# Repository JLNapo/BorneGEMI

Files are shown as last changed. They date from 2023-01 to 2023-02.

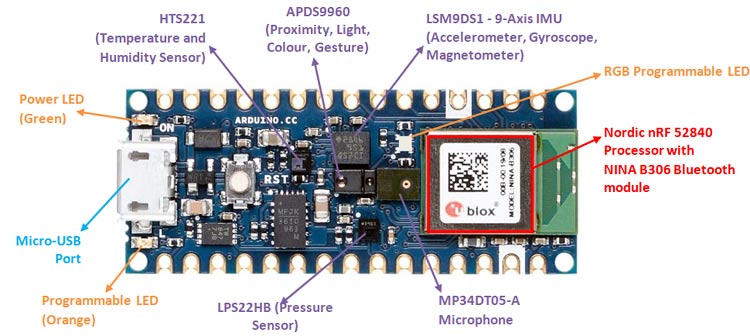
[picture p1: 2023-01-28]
Images/Nano-33-BLE-Sense-Hardware-Overview.jpg

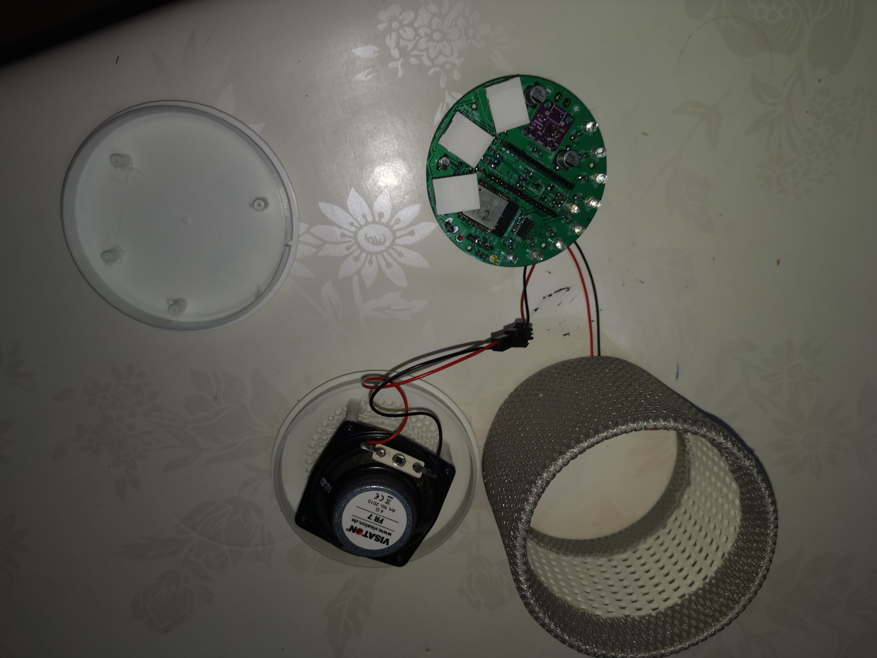
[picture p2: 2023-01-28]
Images/img06.jpg

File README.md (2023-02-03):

# Enceinte-Connectée-Domotique
Créer une enceinte connectée pour votre domotique est possible à moindre frais.

Une enceinte connectée avec peu d'élément et capable de commander votre domotique sans passer par un serveur externe est faisable facilement avec des éléments Arduino et un  peu d'électronique.
Cette borne (appelons la comme cela) est principalement composée de 2 processeurs.
- Un Arduino NANO 33 BLE Sense modèle ABX0035 (maintenant remplacé par ABX0070, même fonctionnement mais librairie différentes)
- Un ESP-WROOM-32 module prenant moins de place que les ESP32 et tout leur système de connexion et programmation.
- Un TTL 74HC595 (registre à décalage) permettant la gestion de 8 LEDs pour le réglage du volume (principalement)
- 9 LEDs dont une RVB piloté par 3 transistors afin de ne pas surcharger les GPIO de l'ESP32
- Quelques resistances
- des connecteurs
- Une alimentation secteur à sortie 5V 1,5A ou plus (1A permet le fonctionnement, mais il est préférable de garder une marge)
- Un haut parleur
- Un boitier fait avec une imprimante 3D (3 pièces)
- Un peu de tissus spécial haut parleur (un tissus à mailles pas très serré peu convenir)

# Logiciels employés:
- Picovoice (https://console.picovoice.ai)
- Voicerss (http://api.voicerss.org)
- Arduino IDE (Ver. 1.8.19.0)
- Sketchup 17 (Google gratuit) boitier 3D
- Cura (Ver. 5.0.0.0) pour le GCode
- Editplus (pour les pages WEB) Notepad++ ou tout autre éditeur peut convenir.
- Kicad 5.0 pour la conception du circuit imprimé (réalisation chez JLCPCB https://jlcpcb.com)

# Librairies ESP32
- WebServer.h
- WiFiClient.h
- WiFi.h
- WiFiMulti.h
- Update.h
- WiFiUdp.h
- "RTClib.h"
- Audio.h
- SPIFFS.h
- HardwareSerial.h
- "ESP8266FtpServer.h"
- "OTApage.h" (données pour la mise à jour par le WEB)
- "esp32_ping.h"

# Librairie NANO 33 BLE Sense
- Picovoice_FR.h (plusieurs langues disponnibles)
- "params.h" (données obtenues sur le site Picovoice)

# Matériel pour le boitier (plusieurs essais) j'ai 4 imprimantes 3D ça aide:
- Imprimante 3D Tenlog TL-D3 Pro
- Artillery Sidewinder X2
- Elegoo Saturn (résine)
- Leapfrog (pas utilisé)
- Tissus Haut Parleur Audio acheté sur Amazon.fr

<b>Nota:</b> toutes imprimantes peut convenir (en tenant compte des dimensions)

Vous trouverez ici l'ensemble de la réalisation ainsi qu'une courte vidéo.
# Réalisation
Cette version est une version beta et correspond à ma domotique qui est quasiment entièrement faite par moi au fil du temps.
J'ai commencé la domotique vers la fin des années 80. Jusque là (et c'est toujours le cas) c'est mon serveur qui tourne 24/7 qui s'en occupait totalement, mais ces dernières années avec l'arrivé des enceintes connectées (j'ai 3 "Google Home" et 2 "Amazon Alexa") mais Google s'est retiré de IFTTT, du coup cela devenait moins pratique pour moi qui ait plus d'objets connectés DIY que du commerce, alors j'ai décidé de créer la mienne et de partager mon expérience avec vous.<br/>
J'en ai construit 3 (pour le moment) qui donne satisfaction au quotidien et sans solliciter aucun serveur externe, certaine réponses des objets connectés sont du texte qui ne peut pas être traité en TTS par l'ESP32, alors j'envoi au serveur Voicerss le texte et je stream le mp3 créé en temps réel sans saturer le SPIFFS de l'ESP32 et la réponse est quasi instantannée. Les commandes et réponses se font au même rytme qu'avec les enceintes connectées du marché mais je n'ai pas recourt à un serveur pour connaitre la commande et l'exécuter (protection des données personnelles)
# Aide
Je suis ouvert à toutes suggestions ou questions et même à une aide (dans la mesure du possible)<br/>
Je peux fournir les fichiers du CI (fichiers Kicad) par exemple.

<b>Nota:</b> Ce partage ne peut en aucun cas faire l'objet de fabrications commerciales, et n'est là qu'a titre ludique pour des amateurs comme moi désireux de garder pour soit des informations qui sont souvent exploitées par les grandes firmes lors de nos commandes vocales par le biais de celles ci.

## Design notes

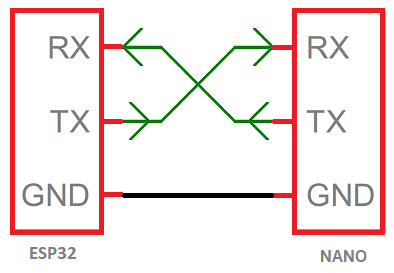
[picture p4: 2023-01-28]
Images/ESP32 Serial communication.png

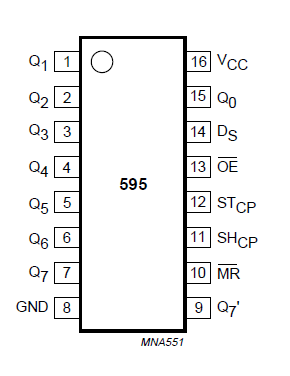
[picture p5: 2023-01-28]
Images/74HC595-01.png

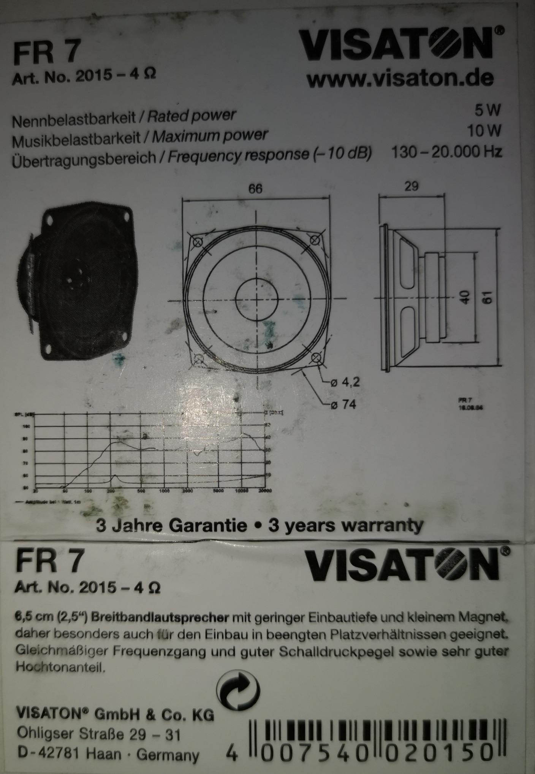
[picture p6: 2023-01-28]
Images/HP-BorneGEMI.jpg

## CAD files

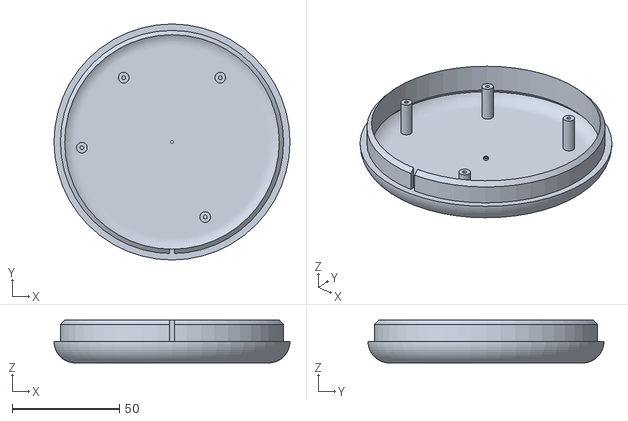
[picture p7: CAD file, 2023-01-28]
Fichiers 3D/BGR_Haut.stl
110.0 x 110.0 x 20.0

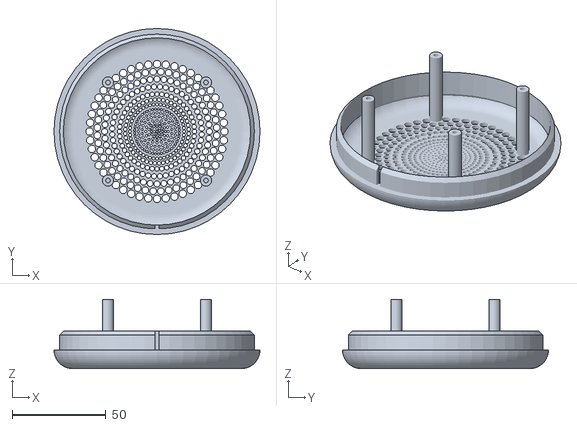
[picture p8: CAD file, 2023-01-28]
Fichiers 3D/BGR_Bas.stl
110.0 x 110.0 x 37.0

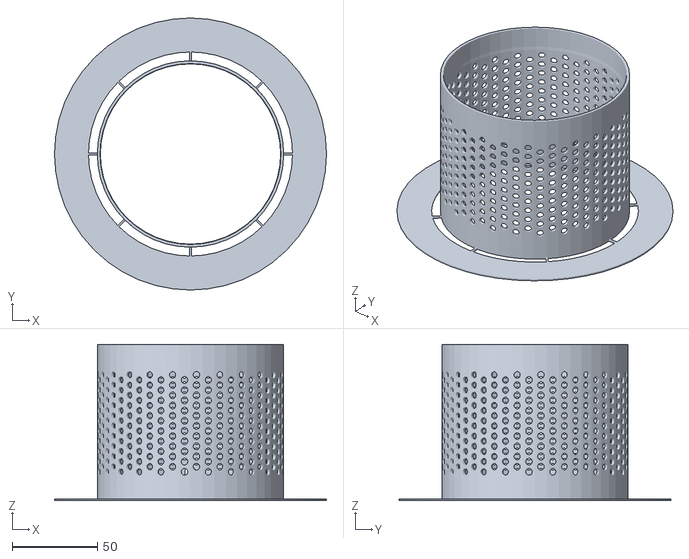
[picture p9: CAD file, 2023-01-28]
Fichiers 3D/BGR_Centre.stl
160.0 x 160.0 x 92.0

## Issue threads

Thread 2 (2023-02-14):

Version 0.2.2.1

JLNapo, 2023-02-14:
Ajout et amélioration de certaines fonctions.
Montage de la quatrième "Borne" avec cette fois un ABX00070 NANO 33 BLE Sense version 2.
Uniformisation des fonctions pour compatibilité ABX00035 et ABX00070.
Très peu de "faux positifs" déclenchés par la radio ou la télévision et ils ne sont de toute façon pas traité (pas de lumière qui s'allume non désirée)

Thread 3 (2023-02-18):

Version 0.2.2.3

JLNapo, 2023-02-18:
Les fonctions d'alarmes, de déclenchement de celles-ci et d'autres fonctions ont été ajoutées.

etiennes33, 2023-12-23:
Bonjour, et félicitations pour ce développement ! J'aimerais bien me lancer dans quelque chose d'équivalent, et j'aurais 2 questions à propos de ce montage.
Quel est approximativement le temps de réponse entre la fin de l'ordre prononcé et l'envoi de la trame correspondante vers l'UART une fois décodé par la carte nano ?
Et surtout, j'ai tenté de m'inscrire sur picovoice, et là surprise, le site n'accepte pas mon email ! Quelle type d'email avez-vous utilisé pour vous inscrire ?
En vous remerciant pour le travail que vous avez accompli et qui va me faire gagner beaucoup de temps :-)

JLNapo, 2023-12-23:
Bonjour,

Le temps de réponse d’une borne est très rapide, si vous avez déjà une borne « Google » ou « Amazon » les temps de réponse sont similaires, sans avoir à communiquer avec un serveur distant.

Le seul serveur auquel je fais appel quand cela est nécessaire, c’est mon serveur domotique situé au sous sol, serveur dans lequel toutes les applications ont été développé par mes soins.

La borne déposée sur forum et github a évoluée, j’en possède 4 et je n’ai jamais eu de fonctionnement non désiré. Il arrive que l’on prononce quelques fois quelques chose proche du mot d’appel (pour moi : « ok GEMI »)

La borne émet le son qui est sensé dire qu’elle attend un ordre, mais si l’ordre n’est pas reconnu (simple conversation ou télé/radio etc.) elle retourne à son état normale d’attente.

Au début je lui faisais dire qu’une erreur était survenue, mais cela peut devenir dérangeant, alors maintenant elle se tait et attend un nouvel ordre (comme les bornes officielle).

Tout cela c’est juste de la programmation, et il faut faire beaucoup d’essai avant de trouver les bons compromis.

Pour picovoice, j’utilise 2 adresses email (chez free) comme cela ça me permet de faire des tests malgré la limitation du nombre autorisé par mois.

Au début Picovoice autorisait un nombre illimité, mais il sont rapidement parvenu à une limitation, car la vente de leurs fonctions est leur gagne pain.

Ce qui est pratique, c’est qu’on peut enregistrer ou charger le fichier créé sur le site et on peut ainsi faire des modifications hors ligne (fichier YML, donc texte) et le recharger lors d’un autre essai.

L’inconvénient, c’est que les fichiers permettant la compilation Pour le Nano est déjà précompilé (pour la partie commandes) et qu’on l’ajoute simplement  (en partie) dans notre programme sur le Nano.

Pour le Nano, attention il en existe plusieurs modèle, celui compatible, est seulement le « Nano 33 BLE Sense ».

Il faut utiliser la clé (fournie lors de l’inscription) avec le Numéro de série, obtenu par un programme fourni par le site, car la compilation ne fonctionnera qu’avec ces paramètres (test effectué par moi)

Il m’ont aussi demander de faire paraitre mon expérience en utilisant leurs fonctions, je leur ait répondu que je n’étais sur aucun réseau social (et je ne compte pas y être de si tôt)

Mais dans le soucis de partage (ce que je fais souvent) je donne des tuyaux ça et là sur le net, mais sans jamais rien attendre en retour.

Si je peux aider, c’est toujours avec joie que je le fais, si on est passionné d’électronique ou de développement, on ne compte pas son temps.

Voilà pour les informations demandées, et en vous souhaitant de passer de très bonnes fêtes de fin d’année .

Cordialement,

Jean-Luc

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

etiennes33, 2023-12-23:
Merci pour cette réponse rapide, je vous posais la question de l'email
car j'ai une adresse free et une autre yahoo, et aucune n'est acceptée.
D'ailleurs en faisant beaucoup d'essais, je me suis rendu compte
qu'aucune adresse issue des grands pourvoyeurs d'adresse (orange, free,
yahoo, gmail, etc...) n'est acceptée. Seules sont acceptées les adresses
de sociétés, je vais donc devoir aviser.

J'ai vu qu'il existe maintenant plusieurs versions du Nano 33 BLE Sense,
notamment ABX00031, ABX00032, ABX00034, ABX00069, ABX00070. Compliqué de
s'y retrouver là-dedans. Lesquels avez-vous utilisé et dont je serai
certain qu'ils fonctionnent , pour que j'évite de chercher un bug
pendant des heures ?

Encore merci pour ce projet, car s'il existe beaucoup de pages internet
sur le sujet, il y a beaucoup de bla-bla et de pub, mais il est
difficile de trouver une vraie réalisation qui fonctionne ! En fait, je
n'ai trouvé que la vôtre qui comporte des sources utilisables ...

Et passez de bonne fêtes de fin d'année !

Etienne

Le 2023-12-23 14:09, JLNapo a écrit :

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

Links:
------
[1] https://github.com/JLNapo/BorneGEMI/issues/3#issuecomment-1868291579
[2]
https://github.com/notifications/unsubscribe-auth/BE4CWXFP77WCDMJTSWAPL3TYK3JXJAVCNFSM6AAAAAAVAHLYI6VHI2DSMVQWIX3LMV43OSLTON2WKQ3PNVWWK3TUHMYTQNRYGI4TCNJXHE
--=_0aaed55ec9d0f3b734d613766a375867
Content-Type: multipart/related;
 boundary="=_70d6374599e5a1d67da88dd9bc7d7d4b"

--=_70d6374599e5a1d67da88dd9bc7d7d4b
Content-Transfer-Encoding: quoted-printable
Content-Type: text/html; charset=UTF-8

<html><head><meta http-equiv=3D"Content-Type" content=3D"text/html; charset=
=3DUTF-8" /></head><body style=3D'font-size: 10pt; font-family: Verdana,Gen=
eva,sans-serif'>
<p>Merci pour cette r&eacute;ponse rapide, je vous posais la question de l'=
email car j'ai une adresse free et une autre yahoo, et aucune n'est accept&=
eacute;e. D'ailleurs en faisant beaucoup d'essais, je me suis rendu compte =
qu'aucune adresse issue des grands pourvoyeurs d'adresse (orange, free, yah=
oo, gmail, etc...) n'est accept&eacute;e. Seules sont accept&eacute;es les =
adresses de soci&eacute;t&eacute;s, je vais donc devoir aviser.</p>
<p>J'ai vu qu'il existe maintenant plusieurs versions du Nano 33 BLE Sense,=
 notamment ABX00031, ABX00032, ABX00034, ABX00069, ABX00070. Compliqu&eacut=
e; de s'y retrouver l&agrave;-dedans. Lesquels avez-vous utilis&eacute; et =
dont je serai certain qu'ils fonctionnent , pour que j'&eacute;vite de cher=
cher un bug pendant des heures ?</p>
<p>Encore merci pour ce projet, car s'il existe beaucoup de pages internet =
sur le sujet, il y a beaucoup de bla-bla et de pub, mais il est difficile d=
e trouver une vraie r&eacute;alisation qui fonctionne ! En fait, je n'ai tr=
ouv&eacute; que la v&ocirc;tre qui comporte des sources utilisables ...</p>
<p>Et passez de bonne f&ecirc;tes de fin d'ann&eacute;e !</p>
<p>Etienne</p>
<p><br /></p>
<p><br /></p>
<p><br /></p>
<p id=3D"reply-intro">Le 2023-12-23 14:09, JLNapo a &eacute;crit&nbsp;:</p>
<blockquote type=3D"cite" style=3D"padding: 0 0.4em; border-left: #1010ff 2=
px solid; margin: 0">
<div id=3D"replybody1">
<p><br /></p>
Bonjour, <br /><br /><br /><br />Le temps de r&eacute;ponse d'une borne est=
 tr&egrave;s rapide, si vous avez d&eacute;j&agrave; une borne &laquo; Goog=
le &raquo; ou &laquo; Amazon &raquo; les temps de r&eacute;ponse sont simil=
aires, sans avoir &agrave; communiquer avec un serveur distant. <br /><br /=
>Le seul serveur auquel je fais appel quand cela est n&eacute;cessaire, c'e=
st mon serveur domotique situ&eacute; au sous sol, serveur dans lequel tout=
es les applications ont &eacute;t&eacute; d&eacute;velopp&eacute; par mes s=
oins. <br /><br />La borne d&eacute;pos&eacute;e sur forum et github a &eac=
ute;volu&eacute;e, j'en poss&egrave;de 4 et je n'ai jamais eu de fonctionne=
ment non d&eacute;sir&eacute;. Il arrive que l'on prononce quelques fois qu=
elques chose proche du mot d'appel (pour moi : &laquo; ok GEMI &raquo;) <br=
 /><br />La borne &eacute;met le son qui est sens&eacute; dire qu'elle atte=
nd un ordre, mais si l'ordre n'est pas reconnu (simple conversation ou t&ea=
cute;l&eacute;/radio etc.) elle retourne &agrave; son &eacute;tat normale d=
'attente. <br /><br />Au d&eacute;but je lui faisais dire qu'une erreur &ea=
cute;tait survenue, mais cela peut devenir d&eacute;rangeant, alors mainten=
ant elle se tait et attend un nouvel ordre (comme les bornes officielle). <=
br /><br />Tout cela c'est juste de la programmation, et il faut faire beau=
coup d'essai avant de trouver les bons compromis. <br /><br /><br /><br />P=
our picovoice, j'utilise 2 adresses email (chez free) comme cela &ccedil;a =
me permet de faire des tests malgr&eacute; la limitation du nombre autoris&=
eacute; par mois. <br /><br />Au d&eacute;but Picovoice autorisait un nombr=
e illimit&eacute;, mais il sont rapidement parvenu &agrave; une limitation,=
 car la vente de leurs fonctions est leur gagne pain. <br /><br />Ce qui es=
t pratique, c'est qu'on peut enregistrer ou charger le fichier cr&eacute;&e=
acute; sur le site et on peut ainsi faire des modifications hors ligne (fic=
hier YML, donc texte) et le recharger lors d'un autre essai. <br /><br />L'=
inconv&eacute;nient, c'est que les fichiers permettant la compilation Pour =
le Nano est d&eacute;j&agrave; pr&eacute;compil&eacute; (pour la partie com=
mandes) et qu'on l'ajoute simplement (en partie) dans notre programme sur l=
e Nano. <br /><br />Pour le Nano, attention il en existe plusieurs mod&egra=
ve;le, celui compatible, est seulement le &laquo; Nano 33 BLE Sense &raquo;=
=2E <br /><br />Il faut utiliser la cl&eacute; (fournie lors de l'inscripti=
on) avec le Num&eacute;ro de s&eacute;rie, obtenu par un programme fourni p=
ar le site, car la compilation ne fonctionnera qu'avec ces param&egrave;tre=
s (test effectu&eacute; par moi) <br /><br />Il m'ont aussi demander de fai=
re paraitre mon exp&eacute;rience en utilisant leurs fonctions, je leur ait=
 r&eacute;pondu que je n'&eacute;tais sur aucun r&eacute;seau social (et je=
 ne compte pas y &ecirc;tre de si t&ocirc;t) <br /><br />Mais dans le souci=
s de partage (ce que je fais souvent) je donne des tuyaux &ccedil;a et l&ag=
rave; sur le net, mais sans jamais rien attendre en retour. <br /><br />Si =
je peux aider, c'est toujours avec joie que je le fais, si on est passionn&=
eacute; d'&eacute;lectronique ou de d&eacute;veloppement, on ne compte pas =
son temps. <br /><br /><br /><br />Voil&agrave; pour les informations deman=
d&eacute;es, et en vous souhaitant de passer de tr&egrave;s bonnes f&ecirc;=
tes de fin d'ann&eacute;e . <br /><br />Cordialement, <br /><br />Jean-Luc =
<br /><br /><br /><br /><br /><br />De : etiennes33 ***@***.*** <br />Envoy=
&eacute; : samedi 23 d&eacute;cembre 2023 13:28 <br />&Agrave; : JLNapo/Bor=
neGEMI <br />Cc : JLNapo; Author <br />Objet : Re: [JLNapo/BorneGEMI] Versi=
on 0.2.2.3 (Issue #3) <br /><br /><br /><br />Bonjour, et f&eacute;licitati=
ons pour ce d&eacute;veloppement ! J'aimerais bien me lancer dans quelque c=
hose d'&eacute;quivalent, et j'aurais 2 questions &agrave; propos de ce mon=
tage. <br />Quel est approximativement le temps de r&eacute;ponse entre la =
fin de l'ordre prononc&eacute; et l'envoi de la trame correspondante vers l=
'UART une fois d&eacute;cod&eacute; par la carte nano ? <br />Et surtout, j=
'ai tent&eacute; de m'inscrire sur picovoice, et l&agrave; surprise, le sit=
e n'accepte pas mon email ! Quelle type d'email avez-vous utilis&eacute; po=
ur vous inscrire ? <br />En vous remerciant pour le travail que vous avez a=
ccompli et qui va me faire gagner beaucoup de temps :-) <br /><br />&mdash;=
 <br />Reply to this email directly, view it on GitHub &lt;https://github.c=
om/JLNapo/BorneGEMI/issues/3#issuecomment-1868284471&gt; , or unsubscribe &=
lt;https://github.com/notifications/unsubscribe-auth/ABOHRTFVNPZBLX2UO7GCWD=
3YK3E3FAVCNFSM6AAAAAAVAHLYI6VHI2DSMVQWIX3LMV43OSLTON2WKQ3PNVWWK3TUHMYTQNRYG=
I4DINBXGE&gt; . <br />You are receiving this because you authored the threa=
d. &lt;https://github.com/notifications/beacon/ABOHRTC4Z2GFJPNGFRVSHK3YK3E3=
FA5CNFSM6AAAAAAVAHLYI6WGG33NNVSW45C7OR4XAZNMJFZXG5LFINXW23LFNZ2KUY3PNVWWK3T=
UL5UWJTTPLPBDO.gif&gt; Message ID: ***@***.***&gt; <br /><br />
<p style=3D"font-size: small; -webkit-text-size-adjust: none; color: #666;"=
>&mdash;<br />Reply to this email directly, <a href=3D"https://github.com/J=
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

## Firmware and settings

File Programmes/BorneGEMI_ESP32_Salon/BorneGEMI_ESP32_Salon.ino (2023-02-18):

/*
 * Gestion de la borne *** Salon
 * Cette partie de la borne execute les commandes et correspond avec *** pour celles qu'il ne peut traiter.
 *
 * Processeur ESP32 (DOIT ESP32 DEVKIT V1)
 * Amplificateur: MAX98357A (3w)
 * LED pilotées par : 74HC595 (8-bit serial - in / serial or parallel - out shift register with output latches 3 - state)
 * Touches sensitives
 *
 * Proc. IDE arduino  : DOIT ESP32 DEVKIT V1
 * Proc. RTC (heure)  : DS3231 (sauvegardé par batterie)
 * Mot de passe WEB   : ***
 * Mot de passe MAJ   : ***
 *
 * IMPORTANT: - Remplacer "***" par vos données.
 *            - Remplacer GEMI ou gémi par le nom de votre système domotique
 *
 */

#include <WebServer.h>
#include <WiFiClient.h>
#include <WiFi.h>
#include <WiFiMulti.h>
#include <Update.h>
#include <WiFiUdp.h>
#include "RTClib.h"
#include <Audio.h>
#include <SPIFFS.h>
#include <HardwareSerial.h>
#include "ESP8266FtpServer.h"
#include "OTApage.h"
#include "esp32_ping.h"

/* Necessaire au Réseau WiFi */
String SysDomo = "GEMI";                                                              // Nom donné au système domotique (pour moi GEMI => Gestion Electronique de Maison Individuelle)
String MyName = SysDomo + "_Salon";                                                   // Nom visible sur le réseau <= Si nécessaire la fonction ESP.getChipId() peut ajouter l'ID de la puce à la fin.
int nbReseauWiFi = 4;                                                                 // Nombre de réseaux disponnibles dans le lieu (pour moi 4)
String ssid1 = "WiFi_1";                                                              // SSID (Nom du reseau wifi)
String pass1 = "MDP WiFi 1";                                                          // Password (Mot de passe wifi)
String ssid2 = "WiFi_2";                                                              // SSID (Nom du reseau wifi)
String pass2 = "MDP WiFi 2";                                                          // Password (Mot de passe wifi)
String ssid3 = "WiFi_3";                                                              // SSID (Nom du reseau wifi)
String pass3 = "MDP WiFi 3";                                                          // Password (Mot de passe wifi)
String ssid4 = "WiFi_4";                                                              // SSID (Nom du reseau wifi)
String pass4 = "MDP WiFi 4";                                                          // Password (Mot de passe wifi)
IPAddress ipAdresse(192, 168, ***, ***);                                              // IP locale de ce module (fourni par le serveur dns, normalement la Box)
IPAddress gateway(192, 168, ***, ***);                                                // L'IP de la box
IPAddress subnet(255, 255, 255, 0);                                                   // Mask réseau
IPAddress dns(192, 168, ***, ***);                                                    // L'IP de la box (ou d'un serveur NTP)
const uint32_t connectTimeoutMs = 10000;                                              // Tmeout de connexion WiFiMulti
String MyIP = "";                                                                     // Contient l'adresse IP avec séparateur (point) comme chaine
String MAC = "";                                                                      // Adresse MAC du module (peut servir pour éventuellement paramétrer la box)
String MySSID = "";
String MyPass = "";
String FTPuser = "Utilisateur FTP";                                                   // Utilisateur FTP
String FTPpass = "MDP FTP";                                                           // Mot de passe FTP
String OTApass = "MDP OTA";                                                           // Mot de passe OTA
char USR_WEB[] = "Utilisateur WEB";                                                   // Utilisateur pour le web (indispensable)
char PSS_WEB[] = "MDP WEB";                                                           // Mot de passe pour le web (indispensable)
bool Log = false;                                                                     // Enregistrer dans un fichier Log les différentes actions
byte LogMois = 0;                                                                     // Mois en cours pour les Log

String VoiceRss = F("http://api.voicerss.org/?key=***&hl=fr-fr&c=MP3&f=32khz_16bit_mono&src=");
String UID_Nano = F("***");
String Access_Key = F("***");

/************************************** CE QUI EST AU DESSUS DE CETTE LIGNE EST SPECIFIQUE A CHAQUE BORNE, AU DESSOUS TOUT EST COMMUN A TOUTES LES BORNES *******************************************************/

const char Version[] = "0.2.2.3";

/* I2S Connexion et boutons */
#define I2S_DOUT        25                                                            // I2S pour la connexion avec l'ampli MAX98357A
#define I2S_BCLK        26
#define I2S_LRC         27
#define Serial_RX       16                                                            // 16 et 17 servent au port série de communication avec le NANO 33 BLE Sense
#define Serial_TX       17
#define bgClock         13                                                            // Clock du 74HC595 (BarGraph)
#define bgLatch         12                                                            // Latch du 74HC595 (BarGraph)
#define bgData          14                                                            // Data  du 74HC595 (BarGraph)
#define btnPlus         19                                                            // Bouton "plus" volume (Touche sensitive capacitive)
#define btnMoins        18                                                            // Bouton "moins" volume (Touche sensitive capacitive)
#define btnMicro        23                                                            // Bouton Arrêt/Marche micro (en réalité pas d'interprétation de ce qui est entendu) (Touche sensitive capacitive)
#define ledMicro        33                                                            // (Rvb) LED Arrêt/Marche micro (en réalité pas d'interprétation de ce qui est entendu) (partie rouge de la LED RVB)
#define ledEcoute       32                                                            // (rvB) LED Arrêt/Marche écoute (allumé avec "Hé! GÉMI" et s'éteint après la commande ou l'abandon utilisateur après ~5/6s ou commande non comprise (avec message).
#define ledWiFi         15                                                            // (rVb) Allumée pendant la mise à l'heure ou la connexion WiFi (verte)
                                                                                      // Etat des couleurs de la LED RVB => Rouge = micro coupé (juste pas d'analyse). Bleu = écoute de cde. Verte = Pas de WiFi ou Mise à l'heure en cours.
/* Diverses variables */
int Volume = 15;                                                                      // Volume par défaut au premier démarrage
int VolDef = 15;                                                                      // Volume par défaut pour certaine réponse importante (ex: alarme arrivée à son terme)
int Grave = 6;                                                                        // Niveau des graves pour le son sortant du haut parleur
int Medium = 4;                                                                       // Niveau des mediums pour le son sortant du haut parleur
int Aigue = -7;                                                                        // Niveau des aigues pour le son sortant du haut parleur
bool VolReg = false;                                                                  // Pour enregistrer après un temps le réglage du volume depuis la borne
bool LedReg = false;                                                                  // Pour l'allumage des leds de volume
int LedVal = 1;                                                                       // Valeur des LEDs allumées
const uint8_t VolumeTable[8]={1, 3, 7, 15, 31, 63, 127, 255};                         // 8 elements (8 LEDs)
bool Micro = true;                                                                    // Micro en fonction (par défaut à true)
unsigned long VolMillis;                                                              // Temporisation avant de sauvegarder la valeur du volume
unsigned long LedMillis;                                                              // Temporisation avant l'exctinction des leds
byte NumStation = 1;                                                                  // Station par défaut
byte NbreRadios = 22;                                                                 // Nombre maxi de Stations de radio
byte NbreBornes = 3;                                                                  // Nombre maxi de bornes domotique
String RadioOld = "";                                                                 // Lien http vers la station de radio en cours.
bool RadioON = false;                                                                 // Passe à true quand la radio marche, sinon false
bool BtnON = false;                                                                   // Flag bouton appuyé
bool TouchON = false;                                                                 // Flag Touche sensitive appuyée
String startString = "";                                                              // Date heure de démarrage
String webString = "";
bool bgReg[8];                                                                        // Registre à décalage du 74HC595
bool bgSens = false;
bool Fait = false;                                                                    // Commande terminée
bool HandShakeWait = false;                                                           // Passe à true si l'ESP32 recois "open" (ouverture d'une commande => le NANO entend "Hé GEMI" et envoi "open" à l'ESP32). L'ESP32 joue le son "on.mp3" et envoi "ready" au NANO (HandShake)
bool HandShakeState = false;                                                          // Statut du HandShake de toute la commande => passe à true au début et ne passe à false que lorsque toute la commande est terminée (réponse de l'objet connecté comprise).
unsigned long HandShakeMillis;                                                        // Pour le timeout du "HandShake" en cas d'un faux positif.
int HandShakeTimeout = 10000;                                                         // Nombre de millisecondes du timeout de la communication NANO/ESP32 ("HandShake")
bool AudioState = false;                                                              // Passe à true au début de lecture d'un MP3 et à false lorsque c'est terminé.
bool Alarme = false;                                                                  // Pour le déclenchement d'une alarme (ex: "mets une alarme dans 10mn" ou "mets une larme à 10H15")
bool AlarmeEtape = false;                                                             // Fait sonner l'alarme une deuxième fois au bout de 5s
uint32_t AlarmeEnSeconde = 0;                                                         // Temps en secondes pour la programmation de l'alarme
float TempOffSet = 0.0;                                                               // OffSet (décalage) de la température mesurée (pour tenir compte de la température dûe au fonctionnement de l'électronique)
bool TestLEDStart = false;                                                            // Faire un test des LEDs au démarrage (oui/non => Defaut: NON) on peut régler ce paramètre ou faire un test depuis la page WEB.

/* functions qui retournent la date en strings (char) en francais */
// Longueur des chaînes pour chaque jour ou mois
#define SECS_PER_HOUR ((time_t)(3600UL))                                              // Necessaire au calcul en fonction de l'heure recueillie par NTP.
#define dt_SHORT_STR_LEN  3                                                           // La longueur des chaînes courtes pour les ou les mois
#define dt_MAX_STRING_LEN 9                                                           // Longueur de la chaîne de date la plus longue (hors null de fin)
static char buffer[dt_MAX_STRING_LEN+1];                                              // Doit être suffisamment grand pour la chaîne la plus longue et la valeur null de fin
const PROGMEM char * const PROGMEM monthNames_P[] = {"Décembre","Janvier","Février","Mars","Avril","Mai","Juin","Juillet","Aout","Septembre","Octobre","Novembre","Décembre"};
const PROGMEM char * const PROGMEM dayNames_P[] = {"Dimanche","Lundi","Mardi","Mercredi","Jeudi","Vendredi","Samedi","Dimanche"};
const char dayShortNames_P[] PROGMEM = "DimLunMarMerJeuVenSam";
const char monthShortNames_P[] PROGMEM = "ErrJanFevMarAvrMaiJunJulAouSepOctNovDec";

char* monthStr(uint8_t month) {
  strcpy_P(buffer, (PGM_P)pgm_read_ptr(&(monthNames_P[month])));
  return buffer;
}

char* monthShortStr(uint8_t month) {
  for (int i=0; i < dt_SHORT_STR_LEN; i++)
    buffer[i] = pgm_read_byte(&(monthShortNames_P[i+ (month*dt_SHORT_STR_LEN)]));
  buffer[dt_SHORT_STR_LEN] = 0;
  return buffer;
}

char* dayStr(uint8_t day) {
  strcpy_P(buffer, (PGM_P)pgm_read_ptr(&(dayNames_P[day])));
  return buffer;
}

char* dayShortStr(uint8_t day) {
  uint8_t index = day*dt_SHORT_STR_LEN;
  for (int i=0; i < dt_SHORT_STR_LEN; i++)
    buffer[i] = pgm_read_byte(&(dayShortNames_P[index + i]));
  buffer[dt_SHORT_STR_LEN] = 0;
  return buffer;
}
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
void loop() {
  server.handleClient();
  ftpSrv.handleFTP();
  now = rtc.now();
  audio.loop();

  /* Changement de jour et forcer une mise à l'heure */
  if (oldJour != now.day()) {                                                         // Tous les jours à 03h03 mise à l'heure pour prise en compte de l'heure Hiver/Eté
    if (oldHeure != now.hour()) {
      if (now.hour() == 3 && now.minute() == 3) {
        oldJour = now.day();
        oldHeure = now.hour();
        HeureOk = false;
        digitalWrite(ledWiFi, HIGH);
      }
    }
  }
  if (now.second() % 10 == 0 && oldSecond != now.second()) {                          // Pour une tentative toutes les 10s
    if (HeureOk == false) {
//      Serial.print(F("Mise à l'heure "));
      time_t dt = getNtpTime();
      if (HeureOk == true) {
        oldJour = now.day();
        oldHeure = now.hour();
        oldSecond = now.second();
//        Serial.println(F("ok"));
//        Serial.println(DateDuJourLong() + " " + twoDigits(now.hour()) + ":" + twoDigits(now.minute()));
        digitalWrite(ledWiFi, LOW);
      } else {
//        Serial.println(F("à faire"));
        oldSecond = now.second();
        digitalWrite(ledWiFi, HIGH);
      }
    }
  }
  /* Gestion du son et du HandShake */
  if (AudioState == true) {
    if (!audio.isRunning()) {
//      Serial.println(F("Audio stop"));
      audio.setVolume(Volume);
      audio.setTone(Grave, Medium, Aigue);
      audio.stopSong();
      AudioState = false;
      if (Fait == true) EnAttenteCde();
      if (HandShakeState == false && HandShakeWait == false) {
//        Serial.println(F("HandShake => false"));
        if (RadioOld != "" && RadioON == true) {
          AudioHost(RadioOld);
        }
      }
    }
  }
  /* Communication HandShake */
  if(SerialNano.available() > 0) {                                                    // Pour dialogue avec NANO BLE Sense
    String r = "";
    while(SerialNano.available()) {
      char s = SerialNano.read();
      r += s;
      Attend(10);
    }
    r.toLowerCase();
    r.trim();
    r.replace("\r", "");
    r.replace("\n", "");
    Serial.print(F("Recu: "));
    Serial.println(r);
    if(Micro == true) {
//      Serial.println(F("Micro ouvert"));
      digitalWrite(ledEcoute, HIGH);
      if (r == "open") {
        audio.stopSong();
        HandShakeWait = true;
        AudioLocalVol("on", VolDef);
        SerialNano.println(F("ready"));
        HandShakeMillis = millis() + HandShakeTimeout;
//        Serial.println(F("Prise en compte"));
      } else if(r != "erreur") {
        audio.stopSong();
        HandShakeMillis = millis() + HandShakeTimeout;
        HandShakeState = true;
//        Serial.println(F("Analyse début"));
        Analyser(r);
//        Serial.println(F("Analyse fin"));
        HandShakeMillis = millis() + HandShakeTimeout;
      } else if (r == "erreur") {
        AudioLocal("erreur");
        Fait = true;
      } else {
//        Serial.println(F("ESP32 n'a pas compris"));
        AudioLocal("pascompris");
        Fait = true;
      }
    } else {
//      Serial.println(F("Micro fermé"));
      HandShakeWait = true;
      if (r == "open") {
        audio.stopSong();
        AudioLocalVol("click", VolDef);
        SerialNano.println(F("ready"));
//        Serial.println(F("Prise en compte"));
      } else if (r != "erreur") {
        if (r.indexOf("micro") > 0) {
//          Serial.println(F("Analyse début"));
          Analyser(r);
//          Serial.println(F("Analyse fin"));
        }
      }
      HandShakeMillis = millis() + HandShakeTimeout;
    }
  }
  /* Timeout du HandShake */
  if (HandShakeState == true || HandShakeWait == true) {
    if (HandShakeMillis < millis()) {
      EnAttenteCde();
    }
  }
  /* Debug et commandes locales */
  if(Serial.available()>0) {                                                          // Pour debug, changer le volume sonore, faire jouer un son ou un streaming
    audio.stopSong();
    String r=Serial.readString(); r.trim();
    r.toLowerCase();
//    Serial.print(F("Recu DEBUG: "));
//    Serial.println(r);
    if (r.startsWith("cde=")) {                                                       // Pour tester une commande (ex: "cde=object:tv,location:séjour,number:5" ou "cde=object:tv,ordre:éteint,location:séjour")
      Analyser(MotPos(r, "=", 2));
    } else if (r.startsWith("vol=")) {
      SetVolume(MotPos(r, "=", 2).toInt());
    } else if (r.startsWith("http")) {
      AudioHost(r);                                                                   // Par exemple: http://cdn.nrjaudio.fm/audio1/fr/40104/mp3_128.mp3 pour Chérie FM
    } else {
      audio.setVolume(Volume);
      AudioLocal(r);
    }
  }
  /* Gestion de l'alarme */
  if(Alarme == true) {
    if (HeureEnSeconde(now.hour(), now.minute(), now.second()) >= AlarmeEnSeconde) {
      AudioLocalVol("alarmeoff", VolDef);
      AlarmeEnSeconde += 5;
      if(AlarmeEtape == false) {
        SupprimeAlarme();
        Alarme = false;
//        Serial.println(F("Fin de l'alarme."));
      }
      AlarmeEtape = false;
    }
  }
  /* Timeout du réglage de volume sonore */
  if(VolReg == true) {
    if(VolMillis < millis()) {
      SauveValeurDefaut();
      AudioLocal("volsave");
      VolReg = false;
//      Serial.println(F("Sauvegarde du volume"));
    }
  }
  /* Exctinction des LEDs après timeout */
  if(LedReg == true) {
    if(LedMillis < millis()) {
      EraseReg();
      LedReg = false;
//      Serial.println(F("Exctinction des LEDs"));
    }
  }
  /* Perte de connexion WiFi */
  if (WiFi.status() != WL_CONNECTED) {
    digitalWrite(ledWiFi, HIGH);
    if(LedMillis < millis()) {
      if (wifiMulti.run(connectTimeoutMs) == WL_CONNECTED) {
        MyIP = IPtoString(WiFi.localIP());
        MySSID = WiFi.SSID();
        digitalWrite(ledWiFi, LOW);
      } else {
        if (bgSens == false) {
          LedVal = LedVal << 1;
          if (LedVal > 128) {
            bgSens = true;
            LedVal = 64;
          }
        } else {
          LedVal = LedVal >> 1;
          if (LedVal < 1) {
            bgSens = false;
            LedVal = 2;
          }
        }
        MakeReg(LedVal);
        LedMillis = millis() + 500;
        LedReg = true;
        MyIP = "";
      }
    }
  } else if (MyIP == "") {
    MyIP = IPtoString(WiFi.localIP());
    MySSID = WiFi.SSID();
    digitalWrite(ledWiFi, LOW);
  }
  /* Gestion des boutons */
  if(digitalRead(btnPlus) == HIGH && BtnON == false) {
    Volume++;
    SetVolume(Volume);
    AudioLocal("beep");
    BtnON = true;
//    Serial.println(F("Bouton plus"));
  }
  if(digitalRead(btnMoins) == HIGH && BtnON == false) {
    Volume--;
    SetVolume(Volume);
    AudioLocal("beep");
    BtnON = true;
//    Serial.println(F("Bouton moins"));
  }
  if(digitalRead(btnMicro) == HIGH && BtnON == false) {
    Micro = !Micro;
    if (Micro == false) {
      digitalWrite(ledMicro, HIGH);
//      Serial.println(F("Micro inactif."));
      AudioLocalVol("micro_off", VolDef);
    } else {
      digitalWrite(ledMicro, LOW);
//      Serial.println(F("Micro actif."));
      LedVolume(Volume);
      LedMillis = millis() + 3000;
      LedReg = true;
      AudioLocalVol("micro_on", VolDef);
    }
    BtnON = true;
//    Serial.println(F("Bouton micro"));
  }
  if (BtnON == true) {
    BtnON = digitalRead(btnPlus) == LOW && digitalRead(btnMoins) == LOW && digitalRead(btnMicro) == LOW ? false : true;
  }
}

void EnAttenteCde() {
  audio.setVolume(Volume);
  if (Micro == true) {
    AudioLocal("off");
  } else {
    AudioLocal("click");
  }
  digitalWrite(ledEcoute, LOW);
  HandShakeState = false;
  HandShakeWait = false;
  Fait = false;
//  Serial.println(F("En attente Cde a été activé."));
}

void Analyser(String Chaine) {
  int nbElement = NbMots(Chaine, ",");
  String Cde = "";
  String Mot1 = "";
  String Mot2 = "";
  String Unite[3];
  uint8_t Valeur[3];
  String Couleur = "";
  String Objet = "";
  String Objet2 = "";
  String Ordre = "";
  String Local = "";
  String Prenom = "";
  String Station = "";
  String Prepos = "";
//  uint32_t Total = 0;
  unsigned Delais;
  // Initialisation des variables
  for(int i=0; i<3; i++) {
    Valeur[i] = 0;
    Unite[i] = "";
  }
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

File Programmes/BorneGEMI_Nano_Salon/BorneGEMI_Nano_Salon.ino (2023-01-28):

/*
 * Pour mémoire :
 *
 * UID: xxxxxxxxxxxxxxxxxxxxxxx                                   => Spécifique à chaque Nano 33 BLE Sense. Obtenu avec le programme donnant cette information indispensable (PicoVoice https://console.picovoice.ai)
 *
 * Key: xxxxxxxxxxxxxxxxxxxxxxxxxxxxxxxxxxxxxxxxxxxxxxxxxxxxxxxx  => Clé de licence d'utilisation gratuite (Obtenu sur le site PicoVoice https://console.picovoice.ai)
 *
 *
 *
 */

#include <Picovoice_FR.h>
#include "params.h"

#define MEMORY_BUFFER_SIZE (70 * 1024)
const char Version[] = "0.1.1";

unsigned long millisEmet;
int Delais = 4000;                                                                        // Délais d'attente maximum du "Ready" émis par l'ESP32

static const char* ACCESS_KEY = "xxxxxxxxxxxxxxxxxxxxxxxxxxxxxxxxxxxxxxxxxxxxxxxxxxxxxx"; // Chaîne Access_Key obtenue à partir de la console Picovoice (https://picovoice.ai/console/)

static pv_picovoice_t *handle = NULL;

static int8_t memory_buffer[MEMORY_BUFFER_SIZE] __attribute__((aligned(16)));

static const float PORCUPINE_SENSITIVITY = 0.75f;
static const float RHINO_SENSITIVITY = 0.5f;

void Attend(int tmp) {
  unsigned long horloge = millis() + tmp;
  while (millis() < horloge) {
    yield();
  }
}

static void wake_word_callback(void) {
  Serial.println("Activation: Hé GEMI");                                                  // Appel reconnu (fonction appelée seulement si l'appel est reconnu)
  Serial1.println("open");                                                                // Commande ouverte, l'ESP32 attend la commande => pour moi GEMI (Gestion Elmectronique de Maison Individuelle)
  digitalWrite(LED_BUILTIN, HIGH);
}

static void inference_callback(pv_inference_t *inference) {
  String Cde = "";

  String r = "";
  millisEmet = millis() + Delais;
  while (r != "ready") {                                                                  // On attend le "Ready" avant de continuer, sinon commande avortée.
    if(millis() > millisEmet) break;
    while (Serial1.available()) {
      char s = Serial1.read();
      r += s;
      r.replace("\r", "");
      r.replace("\n", "");
      r.trim();
      r.toLowerCase();
      millisEmet = millis() + Delais;
    }
  }
  if (r == "") Serial1.println(F("erreur"));                                              // Expression "Ready" non reconnue
  Serial.print(F("R = "));
  Serial.println(r);

  Serial.println("{");
  Serial.print("    Compris : ");
  bool Compris = inference->is_understood;
  Serial.println(Compris == true ? "true" : "false");                                     // Pour le debug
  if (Compris == true) {
    Serial.print("    concerne : ");                                                      // Structure d'un fichier JASON
    Serial.println(inference->intent);
//    Cde = "conserne:" + String(inference->intent);
    if (inference->num_slots > 0) {
      Serial.println("    faire : {");
      for (int32_t i = 0; i < inference->num_slots; i++) {
        Serial.print("        ");
        Serial.print(inference->slots[i]);
        Serial.print(" : ");
        Serial.println(inference->values[i]);
        if (Cde != "") Cde += ",";
        Cde += String(inference->slots[i]) + ":" + String(inference->values[i]);          // Transformation pour mes besoins en une chaine de caractère (pas de JASON à décoder avec l'ESP32
//        Serial1.print(Cde);
      }
//      Serial1.println();
      Serial.println("    }");
      Serial.print(F("Cde = "));
      Serial.println(Cde);
      Serial1.print(Cde);
    }
  } else {
    Serial1.println(F("erreur"));                                                         // Commande incomprise, le mot "erreur" est envoyé à l'ESP32
  }
  Serial.println("}\n");
  digitalWrite(LED_BUILTIN, LOW);
  pv_inference_delete(inference);
}

void setup() {
  Serial.begin(115200);                                                                   // Pour le debug
  //while (!Serial);

  pinMode(LED_BUILTIN, OUTPUT);                                                           // set LED pin as output
  digitalWrite(LED_BUILTIN, LOW);                                                         // switch off LED pin

  Serial1.begin(115200);                                                                  // initialize UART pour dialogue avec ESP32
  //while (!Serial1);                                                                     // Nécessaire uniquement en debug, sinon le NANO attendra indéfiniement

  pv_status_t status = pv_audio_rec_init();
  if (status != PV_STATUS_SUCCESS) {
    Serial.print("Echec de l'initialisation audio avec ");
    Serial.println(pv_status_to_string(status));
    Serial1.println("erreur");                                                            // On signale une erreur à l'ESP32, car l'initialisation du NANO a échoué (ne doit jamais arriver)
    while (1);
  }

  status = pv_picovoice_init (
    ACCESS_KEY,
    MEMORY_BUFFER_SIZE,
    memory_buffer,
    sizeof(KEYWORD_ARRAY),
    KEYWORD_ARRAY,
    PORCUPINE_SENSITIVITY,
    wake_word_callback,
    sizeof(CONTEXT_ARRAY),
    CONTEXT_ARRAY,
    RHINO_SENSITIVITY,
    1.0,
    true,
    inference_callback,
    &handle
  );
  if (status != PV_STATUS_SUCCESS) {
    Serial.print("Echec de l'initialisation de Picovoice avec ");
    Serial.println(pv_status_to_string(status));
    Serial1.println("erreur");                                                            // On signale une erreur à l'ESP32, car l'initialisation de la librairie a échouée (ne doit jamais arriver)
    while (1);
  }

  const char *rhino_context = NULL;
  status = pv_picovoice_context_info(handle, &rhino_context);
  if (status != PV_STATUS_SUCCESS) {
    Serial.print("Echec de la récupération des informations contextuelles avec ");
    Serial.println(pv_status_to_string(status));
    Serial1.println("erreur");                                                            // On signale une erreur à l'ESP32, car l'initialisation de "RHINO" de la librairie a échouée (ne doit jamais arriver)
    while (1);
  }
//  Serial.println("Activation: Salut ordinateur");
  Serial.println("Activation: Hé, GEMI");
  Serial.println(rhino_context);
  Serial.println("\nVer. " + String(Version));
}
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

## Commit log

2023-01-29 Précisions
    Modification de certaines données et images
2023-02-02 Petite évolution
    Le programme ESP32 a été amélioré sur la gestion des alarmes.
    Les pages WEB ont été modifiées pour correspondre à la majorité des besoins de chacun.
    Il faut les ajuster à vos besoins.
2023-02-03 Update README.md
    Ajustement des explications du fonctionnement.
2023-02-14 Version 0.2.2.1
    Gestion des alarmes serveur et gestion de grave, medium et aigue pour le son.
2023-02-18 Amélioration de fonctions
    Les fonctions d'alarmes, de déclenchement de celles-ci et d'autres fonctions ont été ajoutées.
